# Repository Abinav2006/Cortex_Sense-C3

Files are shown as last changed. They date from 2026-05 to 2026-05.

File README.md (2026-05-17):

# CortexSense C3

A compact and intelligent 4-layer IoT development board powered by the ESP32-C3, designed for wireless sensing, environmental monitoring, AI-enabled edge applications, and rapid prototyping.

---

# Why the Name "CortexSense C3"?

The name **CortexSense C3** reflects the core philosophy of the board:

- **Cortex** represents intelligence, processing, and AI-driven capabilities.
- **Sense** highlights the board’s onboard sensing features such as environmental monitoring, ambient light detection, and audio input.
- **C3** refers to the ESP32-C3 microcontroller at the heart of the system.

Together, the name symbolizes an intelligent sensing platform capable of collecting, analyzing, and communicating real-world data.

---

# Overview

CortexSense C3 is a feature-rich embedded development platform combining wireless connectivity, onboard sensors, storage, battery support, and AI integration possibilities into a single compact PCB.

The board is built using a **4-layer PCB architecture** for improved signal integrity, grounding, and power distribution, making it suitable for reliable embedded and IoT applications.

This platform is ideal for:

- Environmental monitoring systems
- Wireless IoT nodes
- Portable data loggers
- AI-assisted embedded systems
- Voice-enabled smart devices
- Battery-powered sensing platforms
- Rapid embedded prototyping

---

# Hardware Features

## Microcontroller

### ESP32-C3
- RISC-V based architecture
- Wi-Fi connectivity
- Bluetooth Low Energy (BLE)
- USB support
- Low power operation
- Suitable for IoT and edge computing applications

---

# Power System

- USB-C power input
- LiPo battery connector
- Onboard 3.3V regulator
- Onboard 5V regulation circuitry
- Battery-powered operation support
- Power management circuitry

Designed for both:
- Portable battery-powered applications
- USB-powered desktop operation

---

# Storage

## MicroSD Card Slot
Supports:
- Sensor data logging
- Offline storage
- Audio recording
- Dataset collection

## External SPI Flash Memory
Useful for:
- Firmware storage
- Local caching
- AI model storage
- Configuration storage

---

# Sensors

## Environmental Sensor — BME280
Measures:
- Temperature
- Humidity
- Atmospheric pressure

Suitable for:
- Weather monitoring
- Indoor air analysis
- Smart agriculture
- Climate tracking

---

## Ambient Light Sensor
Features:
- Light intensity sensing
- Day/night detection
- Automatic brightness applications

---

## Audio Input System
Includes:
- Onboard microphone
- Audio pre-amplifier circuitry

Applications:
- Sound level monitoring
- Voice-controlled systems
- Acoustic analysis
- Smart assistants

---

# Interfaces

- I2C interface
- SPI interface
- GPIO expansion header
- USB-to-UART bridge
- Debug test points

Allows easy integration with:
- Displays
- External sensors
- Actuators
- Wireless modules
- Custom peripherals

---

# User Interaction

- Boot button
- Reset button
- Status LEDs
- GPIO headers

---

# PCB Design

## 4-Layer PCB Architecture

The board uses a professionally designed 4-layer PCB stackup for:

- Improved signal integrity
- Better grounding
- Reduced EMI
- Cleaner power distribution
- Compact routing

Additional design features:
- Dedicated debugging test points
- Optimized component placement
- Modular expansion capability

---

# Potential Applications

## Environmental Monitoring Station

CortexSense C3 can function as a compact weather and environmental monitoring system capable of tracking:

- Temperature
- Humidity
- Pressure
- Ambient light levels

Features include:
- Local logging to microSD
- Wireless cloud upload via Wi-Fi
- Remote monitoring dashboards
- Historical data storage

---

## Portable Data Logger

With battery support and onboard storage, the board is ideal for:

- Field research
- Agricultural monitoring
- Industrial sensing
- Mobile data collection

---

## Smart IoT Devices

The ESP32-C3 enables wireless communication for:

- Smart home systems
- Wireless sensor nodes
- BLE devices
- Remote monitoring applications

---

## Acoustic Monitoring

The onboard microphone system enables:

- Noise pollution monitoring
- Audio event detection
- Voice-triggered systems
- Environmental acoustic analysis

---

## Wearable Electronics

Its compact form factor and LiPo battery support make it suitable for:

- Wearable sensors
- Portable health devices
- Smart badges
- Mobile embedded systems

---

# AI and OpenAI Integration

One of the most exciting exploration areas for CortexSense C3 is embedded Artificial Intelligence.

Espressif provides OpenAI-compatible libraries and components for ESP32 platforms, enabling embedded devices to interact with Large Language Models (LLMs).

This opens the door to intelligent embedded applications capable of understanding and responding naturally.

---

# Voice-Controlled Smart Assistant

Using:
- The onboard microphone
- Wi-Fi connectivity
- OpenAI APIs

CortexSense C3 can become a conversational embedded assistant capable of:

- Understanding natural language
- Responding contextually
- Controlling smart devices
- Providing intelligent sensor analysis

Example interactions:

> “What is the current room temperature?”

> “Why is the humidity unusually high today?”

> “Turn on the lights.”

---

# Intelligent Environmental Insights

Instead of simply displaying raw sensor values, AI integration can:

- Analyze environmental trends
- Detect anomalies
- Generate human-readable summaries
- Recommend actions

Example:

> “Temperature has increased steadily for the last 3 hours. Consider watering the plants.”

---

# Future Improvements

Planned enhancements include:

- TinyML support
- Edge AI inference
- OTA firmware updates
- Display integration
- Additional sensor modules
- Ultra low-power optimization
- Custom enclosure development

---

# Software Support

CortexSense C3 can be programmed using:

- Arduino IDE
- ESP-IDF
- PlatformIO

---

# Recommended Libraries

## Connectivity
- WiFi
- BLE

## Storage
- SD card libraries
- SPIFFS

## Sensors
- BME280 drivers
- I2C utilities

## AI
- OpenAI ESP32 libraries

---

# Project Goals

The objective of CortexSense C3 is to create a flexible and expandable embedded platform for:

- IoT experimentation
- Wireless sensing
- Edge AI applications
- Embedded system learning
- Portable electronics development
- Rapid prototyping

---

# Getting Started

## Requirements

- USB-C cable
- ESP32 board support package
- Arduino IDE / ESP-IDF / PlatformIO
- Required sensor libraries

---

# Basic Workflow

1. Connect the board using USB-C
2. Install ESP32 board packages
3. Open the firmware project
4. Select the correct COM port
5. Build and flash firmware
6. Monitor serial output

---

# Images

## Front View

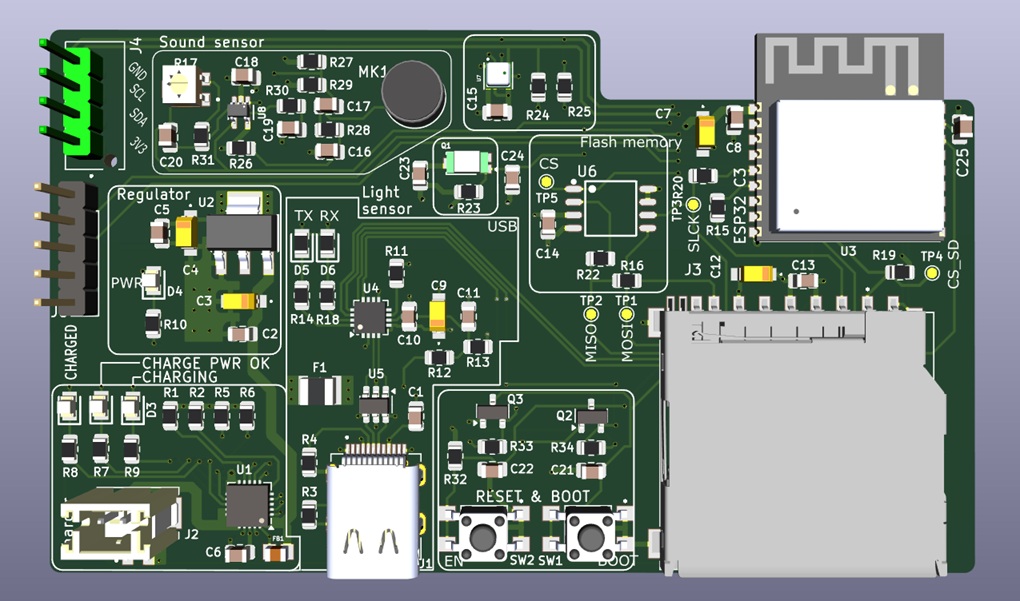
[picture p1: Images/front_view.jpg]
Front View


---

## Back View

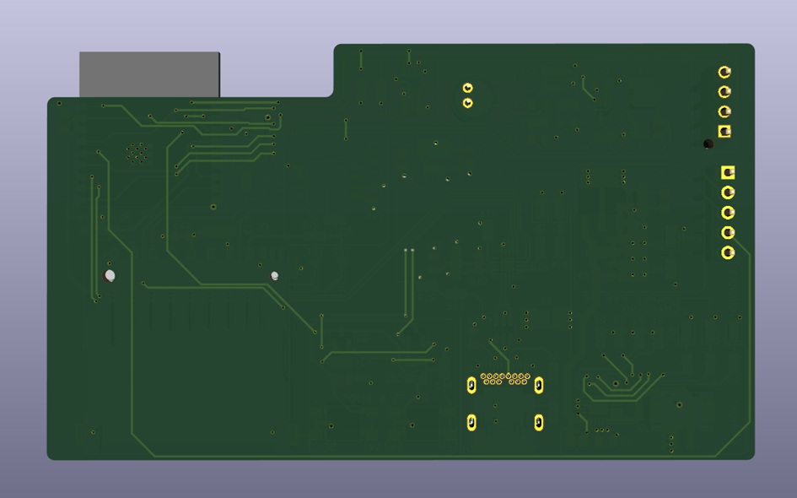
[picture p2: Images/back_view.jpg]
Back View


# License

This project is licensed under the MIT License.

```text
MIT License
```

---

# Acknowledgements

Special thanks to:

- Espressif Systems
- OpenAI
- Open-source embedded community

---

# Status

🚧 Under Active Development

Current Version:
```text
Rev A / v1.0
```

---

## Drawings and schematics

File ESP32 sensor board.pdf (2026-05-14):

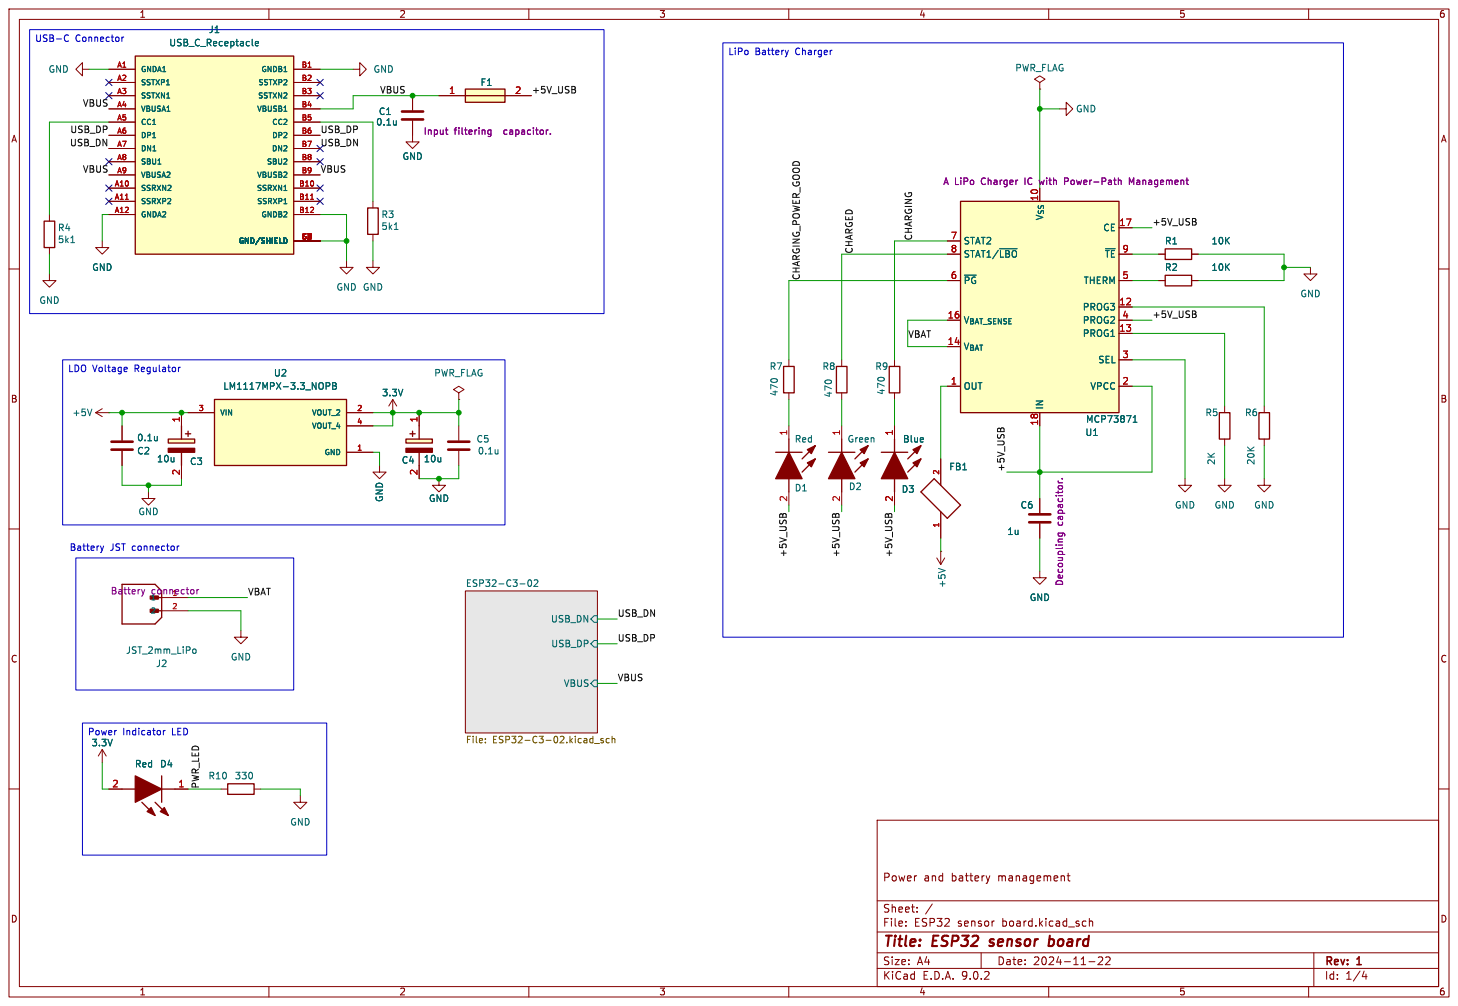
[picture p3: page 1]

1 2 R2 10K U1MCP73871 A LiPo Charger IC with Power-Path Management VPCC 2 SEL 3 PROG1 13 PROG2 4 PROG3 12 THERM 5 ~{TE}9 CE 17 IN 18 V_{SS} 10 OUT 1 V_{BAT} 14 V_{BAT_SENSE} 16 ~{PG} 6 STAT1/~{LBO} 8 STAT2 7 GND

Id: 1/4 Title: ESP32 sensor board

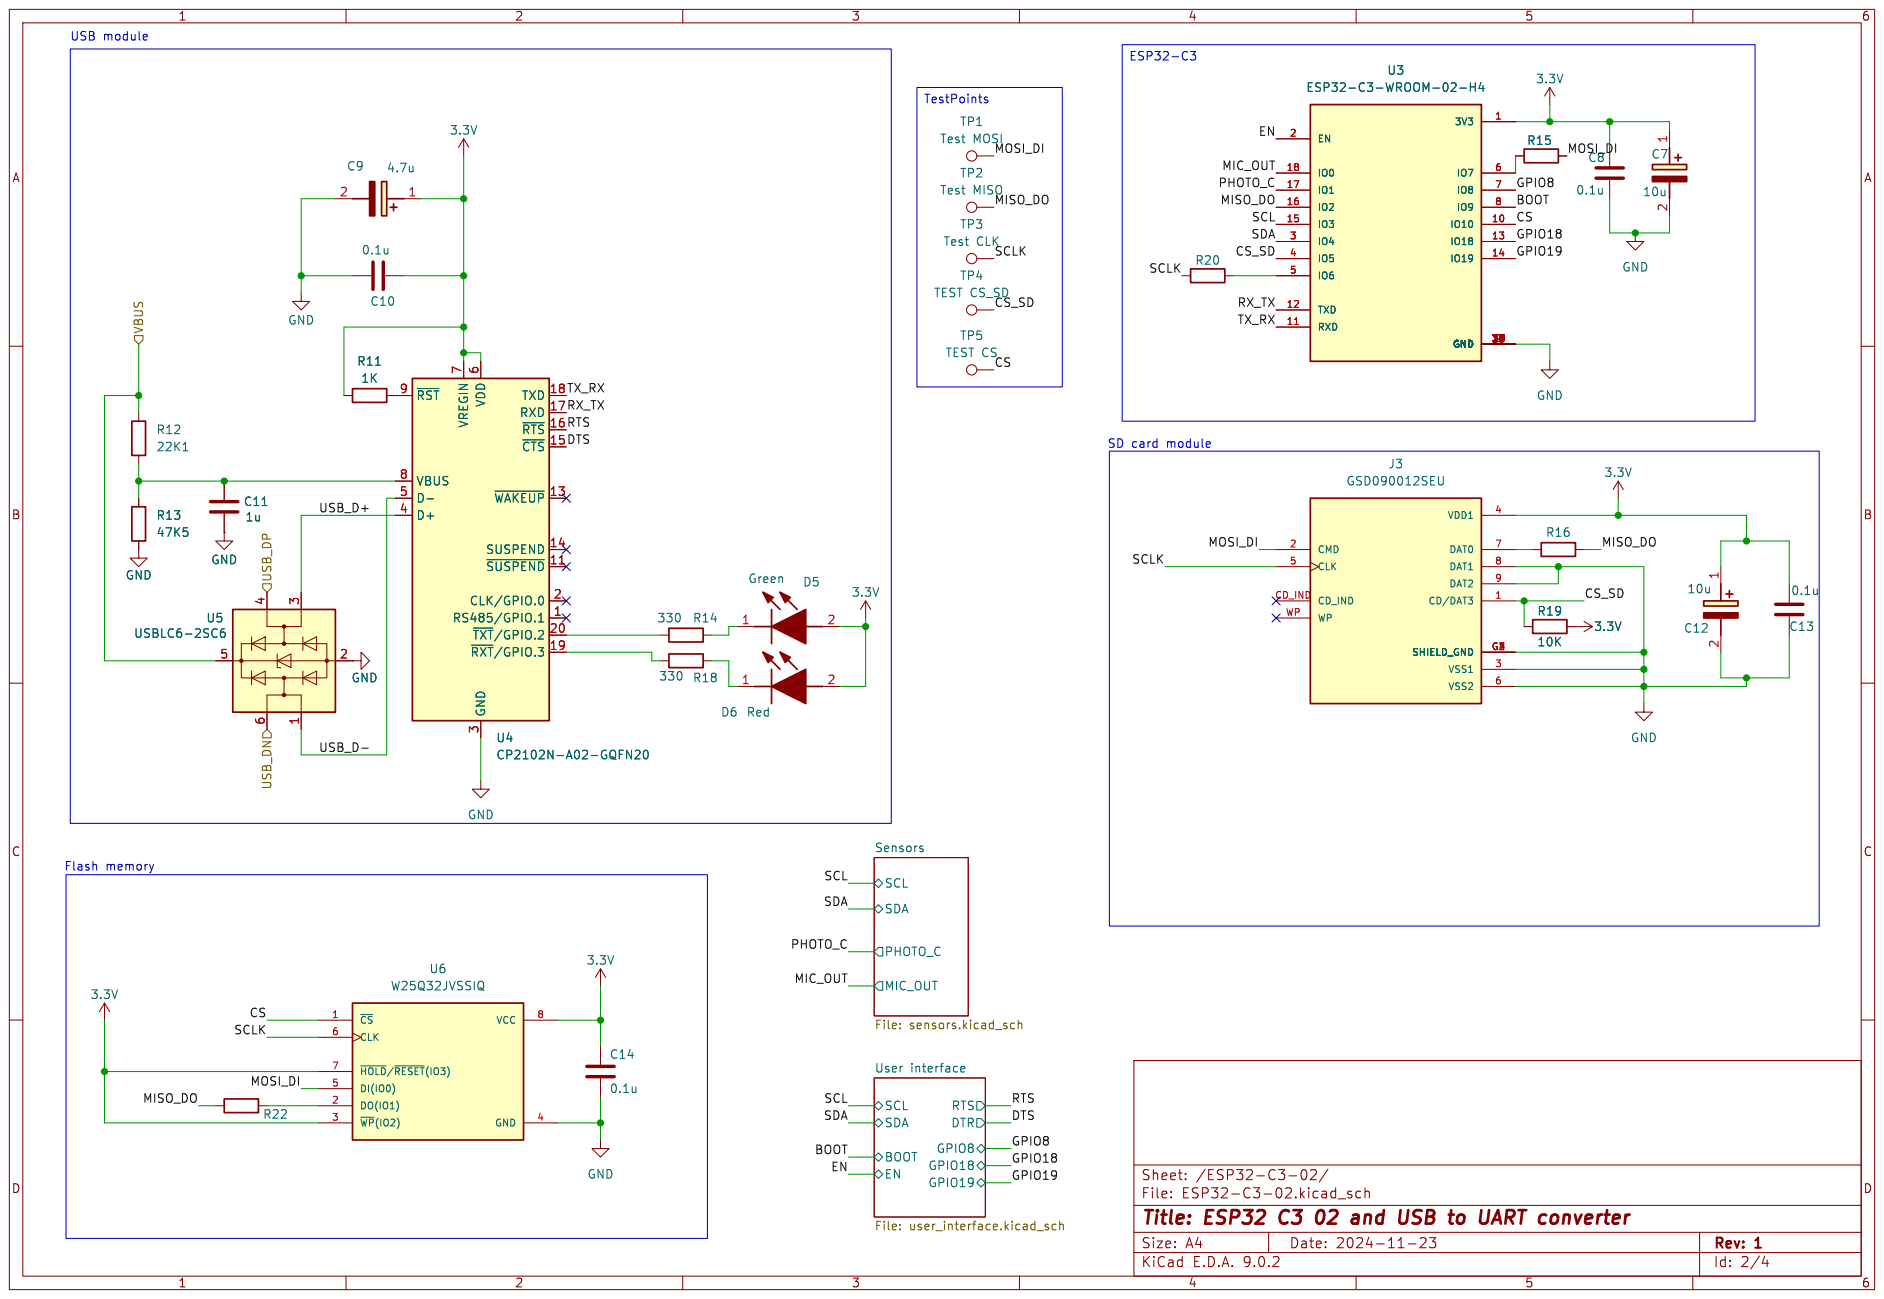
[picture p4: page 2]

TP1 Test MOSI TP2 Test MISO

3 TXD 18 RXD 17 ~{RTS} 16 ~{CTS} 15 ~{WAKEUP} 13 SUSPEND 14 ~{SUSPEND}11 CLK/GPIO.0 2 RS485/GPIO.1 1 ~{TXT}/GPIO.220 ~{RXT}/GPIO.319 C11

3 TXD 18 RXD 17 ~{RTS} 16 ~{CTS} 15 ~{WAKEUP} 13 SUSPEND 14 ~{SUSPEND}11 CLK/GPIO.0 2 RS485/GPIO.1 1 ~{TXT}/GPIO.220 ~{RXT}/GPIO.319 U4 CP2102N-A02-GQFN20 GND

PHOTO_C MIC_OUT Sensors File: sensors.kicad_sch SDA

Id: 2/4 Title: ESP32 C3 02 and USB to UART converter File: ESP32-C3-02.kicad_sch Sheet: /ESP32-C3-02/ SCL SDA
SCL SDA

DTR GPIO8 GPIO18 GPIO19 RTS User interface File: user_interface.kicad_sch
SCL BOOT EN

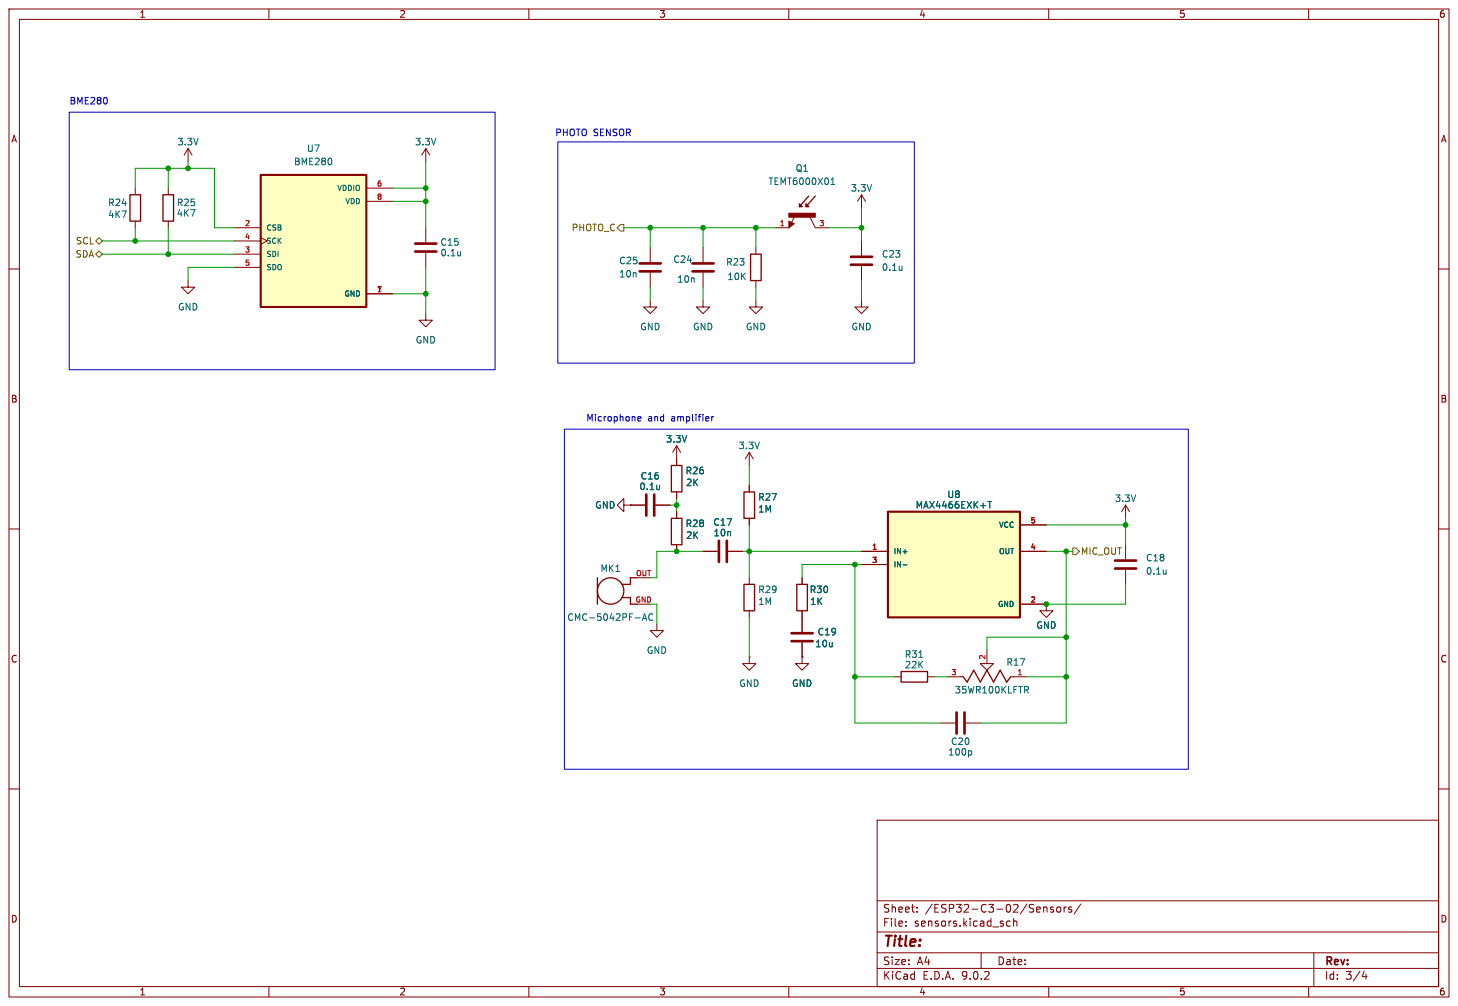
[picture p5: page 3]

OUT GND MK1 CMC-5042PF-AC

Id: 3/4 Title: File: sensors.kicad_sch Sheet: /ESP32-C3-02/Sensors/ 1

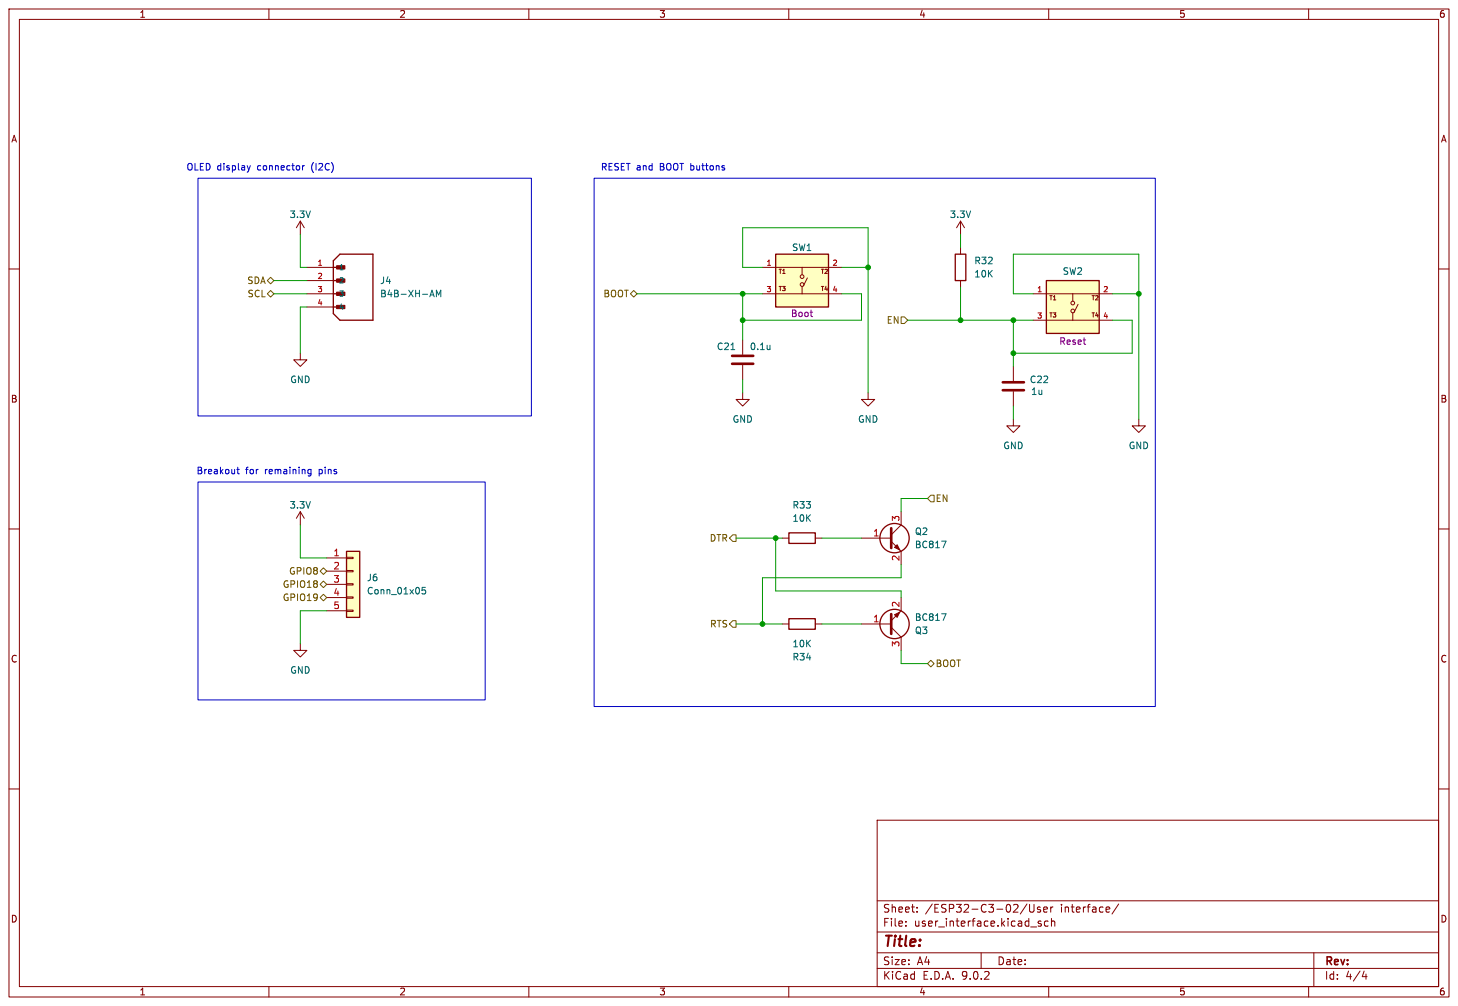
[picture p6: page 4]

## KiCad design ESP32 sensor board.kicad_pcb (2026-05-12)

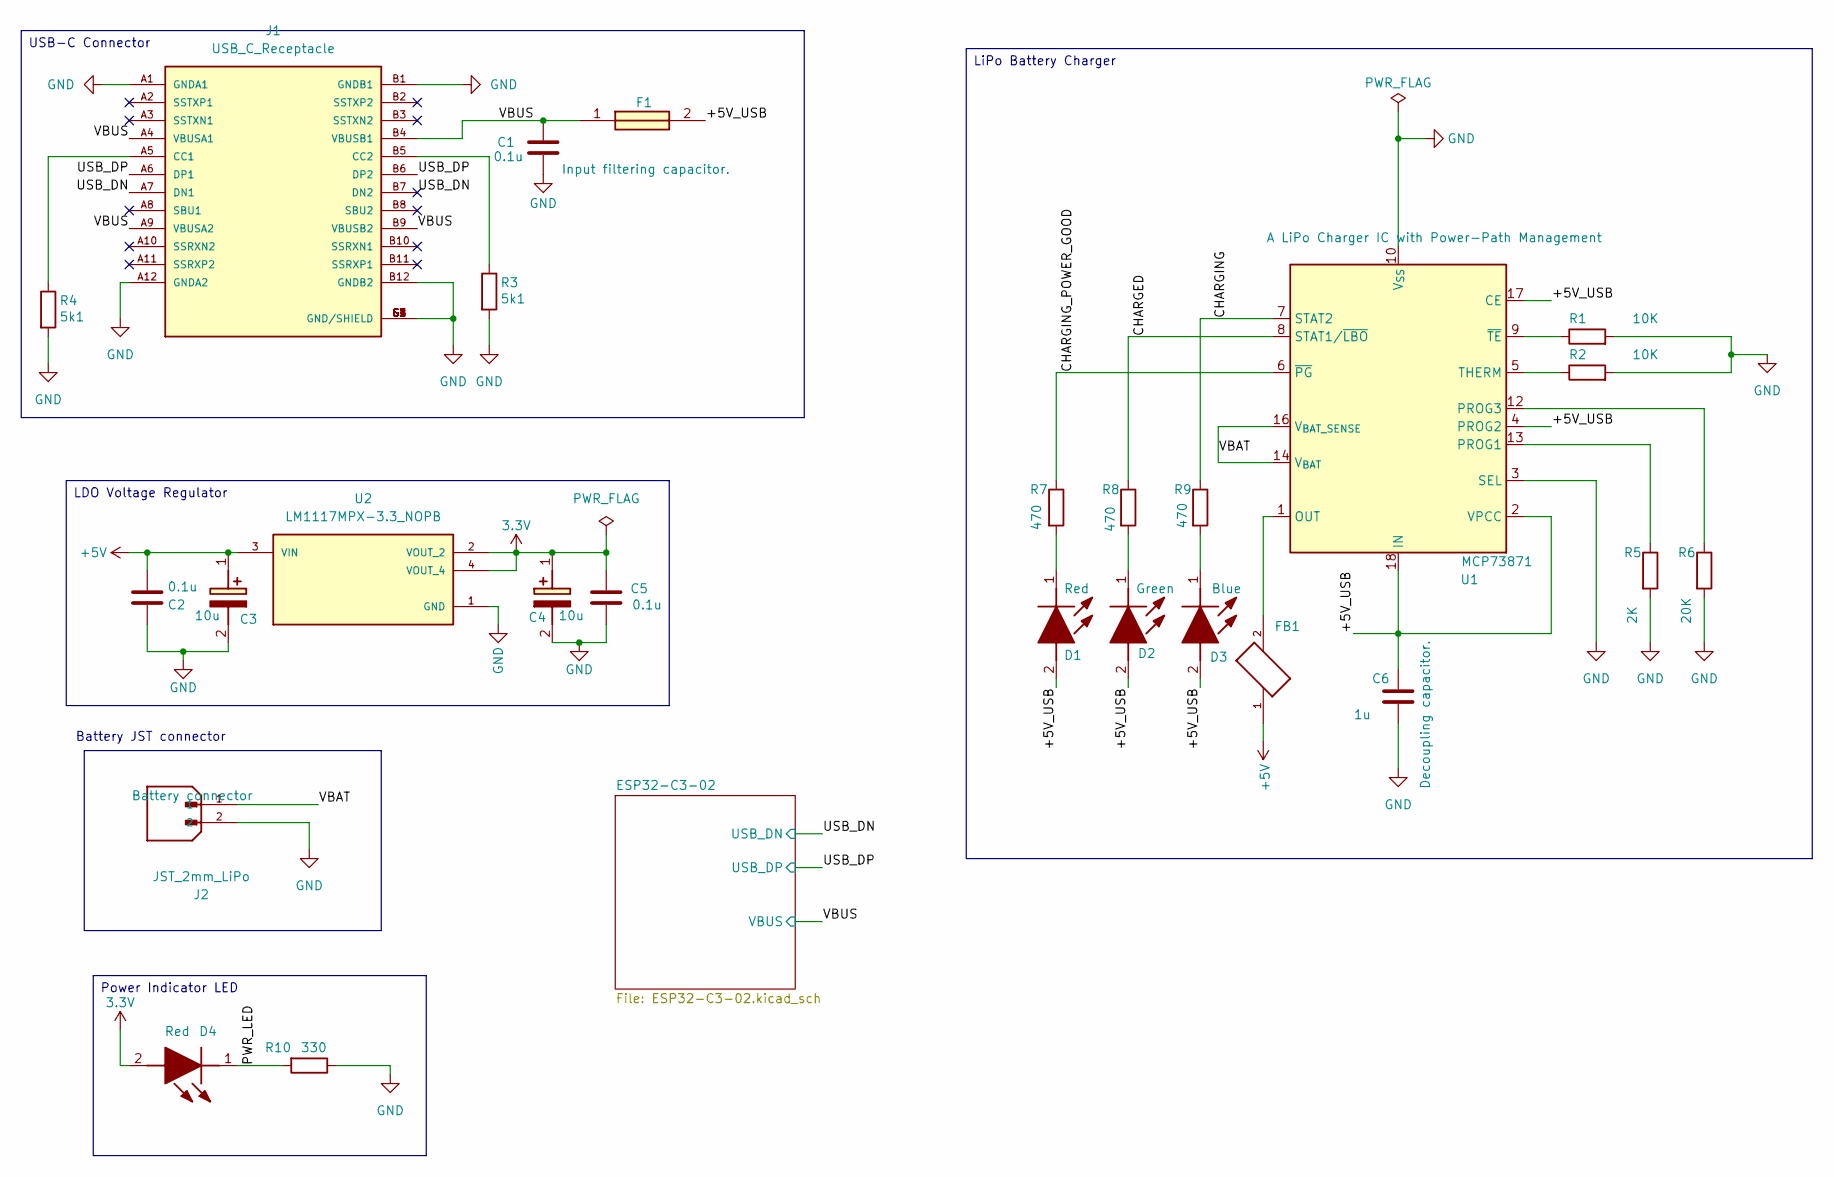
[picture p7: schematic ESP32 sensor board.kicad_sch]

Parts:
C1, C2, C5: 0.1u; C_0805_2012Metric; Voltage 1kV; Tolerance 100%
C3, C4: 10u; T491A; Voltage 1kV; Tolerance 100%; Manufacturer_Part_Number T491A106K010AT7280; Mouser Part Number 80-T491A106K107280
C6: 1u; C_0805_2012Metric; Voltage 1kV; Tolerance 100%
D1, D4: Red; LEDC2012X120N; Manufacturer_Part_Number LTST-C170KRKT; Mouser Part Number 859-LTST-C170KRKT
D2: Green; LEDC2012X120N; Manufacturer_Part_Number LTST-C170GKT; Mouser Part Number 859-LTST-C170GKT
D3: Blue; LEDC2012X120N; Manufacturer_Part_Number LTST-C170TBKT; Mouser Part Number 859-LTST-C170TBKT
F1: 0ZCH0110AF2E; FUSC3226X100N; Manufacturer_Part_Number 0ZCH0110AF2E
FB1: FBMJ2125HM330-T; BEADC2012X105N
J1: USB_C_Receptacle; BELFUSE_SS-52400-002; PARTREV A0
J2: JST_2mm_LiPo; JST_B2B-PH-SM4-TB; Manufacturer_Part_Number ?
R1, R2: 10K; R_0805_2012Metric
R3, R4: 5k1; R_0805_2012Metric
R5: 2K; R_0805_2012Metric
R6: 20K; R_0805_2012Metric
R7, R8, R9: 470; R_0805_2012Metric
R10: 330; R_0805_2012Metric
U1: MCP73871; QFN-20-1EP_4x4mm_P0.5mm_EP2.5x2.5mm; Manufacturer_Part_Number MCP73871-4CCI/ML
U2: LM1117MPX-3.3_NOPB; VREG_LM1117MPX-3.3; Mouser Part Number 926-LM1117MPX3.3NOPB

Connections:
3.3V: C4.1 (+), C5.1, D4.2 (A), U2.2 (VOUT_2), U2.4 (VOUT_4); also elsewhere on the board
+5V: C2.1, C3.1 (+), FB1.1, U2.3 (VIN)
/+5V_USB: C6.1, D1.2 (A), D2.2 (A), D3.2 (A), F1.2, U1.2 (VPCC), U1.4 (PROG2), U1.17 (CE), U1.18 (IN), U1.19 (IN)
/CHARGED: R8.1, U1.8 (STAT1/~LBO)
/CHARGING: R9.1, U1.7 (STAT2)
/CHARGING_POWER_GOOD: R7.1, U1.6 (~PG)
/PWR_LED: D4.1 (K), R10.2
/USB_DN: J1.A7 (DN1), J1.B7 (DN2); also elsewhere on the board
/USB_DP: J1.A6 (DP1), J1.B6 (DP2); also elsewhere on the board
/VBAT: J2.1, U1.14 (V_{BAT}), U1.15 (V_{BAT}), U1.16 (V_{BAT_SENSE})
/VBUS: C1.1, F1.1, J1.A4 (VBUSA1), J1.A9 (VBUSA2), J1.B4 (VBUSB1), J1.B9 (VBUSB2); also elsewhere on the board
unnamed: D1.1 (K), R7.2
unnamed: D2.1 (K), R8.2
unnamed: D3.1 (K), R9.2
unnamed: FB1.2, U1.1 (OUT), U1.20 (OUT)
unnamed: J1.A5 (CC1), R4.1
unnamed: J1.B5 (CC2), R3.1
unnamed: R5.1, U1.13 (PROG1)
unnamed: R6.1, U1.12 (PROG3)
unnamed: R2.1, U1.5 (THERM)
unnamed: R1.1, U1.9 (~TE)

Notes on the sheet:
Battery JST connector
LDO Voltage Regulator
LiPo Battery Charger
USB-C Connector
Power Indicator LED

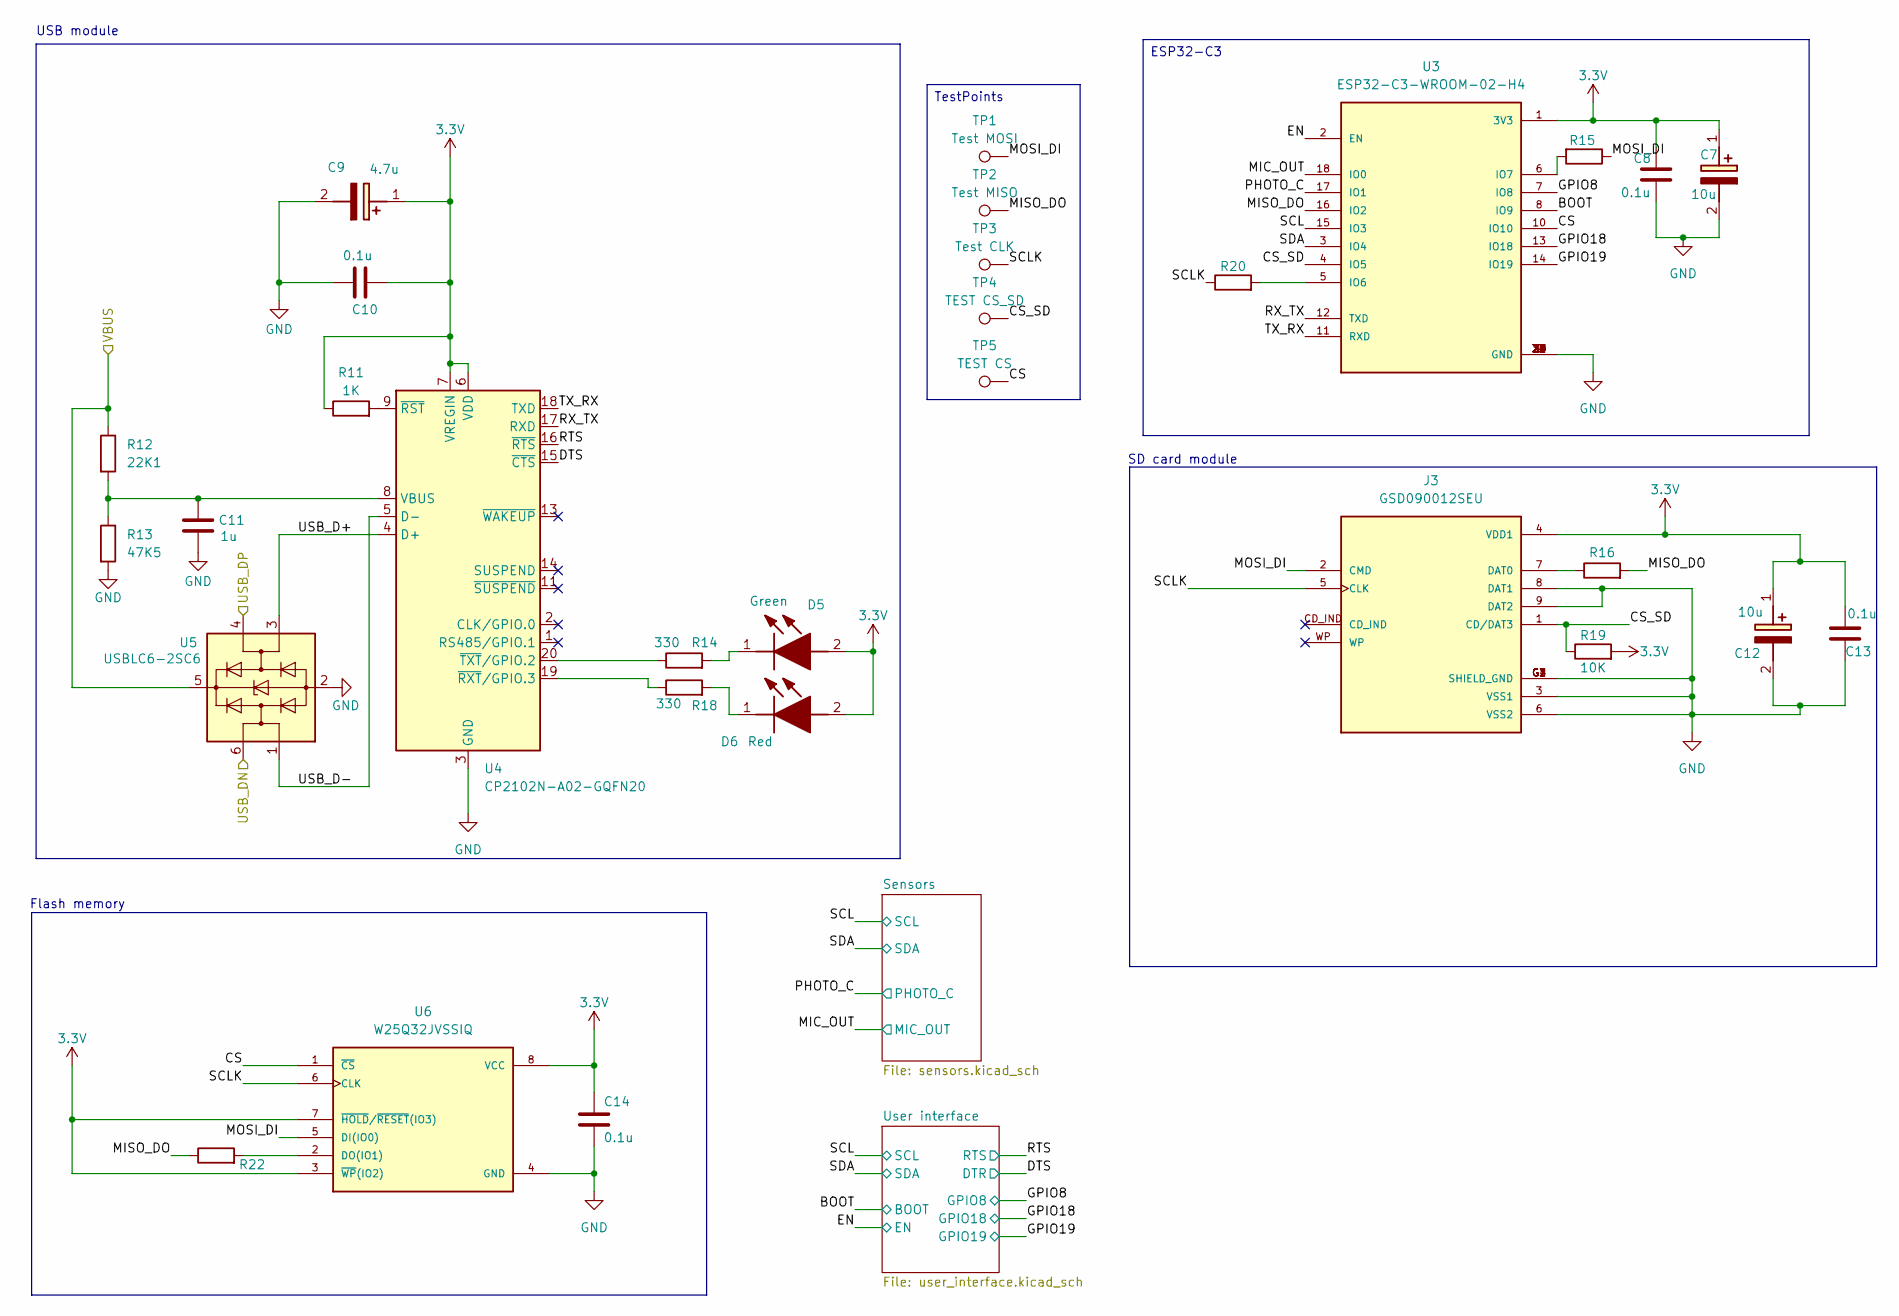
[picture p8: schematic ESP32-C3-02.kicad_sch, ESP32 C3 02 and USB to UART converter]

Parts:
C7, C12: 10u; T491A; Voltage 1kV; Tolerance 100%; Manufacturer_Part_Number T491A106K010AT7280; Mouser Part Number 80-T491A106K107280
C8, C10, C13, C14: 0.1u; C_0805_2012Metric; Voltage 1kV; Tolerance 100%
C9: 4.7u; T491A; Voltage 1kV; Tolerance 100%; Manufacturer_Part_Number T491A106K010AT7280; Mouser Part Number 80-T491A106K107280
C11: 1u; C_0805_2012Metric; Voltage 1kV; Tolerance 100%
D5: Green; LEDC2012X120N; Manufacturer_Part_Number LTST-C170GKT; Mouser Part Number 859-LTST-C170GKT
D6: Red; LEDC2012X120N; Manufacturer_Part_Number LTST-C170KRKT; Mouser Part Number 859-LTST-C170KRKT
J3: GSD090012SEU; AMPHENOL_GSD090012SEU; PARTREV E
R11: 1K; R_0805_2012Metric
R12: 22K1; R_0805_2012Metric
R13: 47K5; R_0805_2012Metric
R14, R18: 330; R_0805_2012Metric
R15, R16, R20, R22: 50; R_0805_2012Metric
R19: 10K; R_0805_2012Metric
TP1: Test MOSI; TestPoint_Pad_D1.0mm
TP2: Test MISO; TestPoint_Pad_D1.0mm
TP3: Test CLK; TestPoint_Pad_D1.0mm
TP4: TEST CS_SD; TestPoint_Pad_D1.0mm
TP5: TEST CS; TestPoint_Pad_D1.0mm
U3: ESP32-C3-WROOM-02-H4; MODULE_ESP32-C3-WROOM-02-H4; Manufacturer_Part_Number ESP32-C3-WROOM-02-H4
U4: CP2102N-A02-GQFN20; SiliconLabs_QFN-20-1EP_3x3mm_P0.5mm_EP1.8x1.8mm; Manufacturer_Part_Number CP2102N-A02-GQFN20
U5: USBLC6-2SC6; SOT-23-6; Manufacturer_Part_Number USBLC6-2SC6; Mouser Part Number 511-USBLC6-2SC6
U6: W25Q32JVSSIQ; SOIC127P790X216-8N; M_PART_NUMBER W25QXX

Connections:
3.3V: C7.1 (+), C8.1, C9.1 (+), C10.1, C12.1 (+), C13.2, C14.1, D5.2 (A), D6.2 (A), J3.4 (VDD1), R11.1, R19.2, U3.1 (3V3), U4.6 (VDD), U4.7 (VREGIN), U6.3 (~WP(IO2)), U6.7 (~HOLD/~RESET(IO3)), U6.8 (VCC); also elsewhere on the board
/ESP32-C3-02/CS: TP5.1, U3.10 (IO10), U6.1 (~CS)
/ESP32-C3-02/CS_SD: J3.1 (CD/DAT3), R19.1, TP4.1, U3.4 (IO5)
/ESP32-C3-02/DTS: U4.15 (~CTS); also elsewhere on the board
/ESP32-C3-02/GPIO8: U3.7 (IO8); also elsewhere on the board
/ESP32-C3-02/GPIO18: U3.13 (IO18); also elsewhere on the board
/ESP32-C3-02/GPIO19: U3.14 (IO19); also elsewhere on the board
/ESP32-C3-02/MIC_OUT: U3.18 (IO0); also elsewhere on the board
/ESP32-C3-02/MISO_DO: R16.2, R22.1, TP2.1, U3.16 (IO2)
/ESP32-C3-02/MOSI_DI: J3.2 (CMD), R15.1, TP1.1, U6.5 (DI(IO0))
/ESP32-C3-02/PHOTO_C: U3.17 (IO1); also elsewhere on the board
/ESP32-C3-02/RTS: U4.16 (~RTS); also elsewhere on the board
/ESP32-C3-02/RX_TX: U3.12 (TXD), U4.17 (RXD)
/ESP32-C3-02/SCL: U3.15 (IO3); also elsewhere on the board
/ESP32-C3-02/SCLK: J3.5 (CLK), R20.1, TP3.1, U6.6 (CLK)
/ESP32-C3-02/SDA: U3.3 (IO4); also elsewhere on the board
/ESP32-C3-02/TX_RX: U3.11 (RXD), U4.18 (TXD)
/ESP32-C3-02/USB_D+: U4.4 (D+), U5.3 (I/O2)
/ESP32-C3-02/USB_D-: U4.5 (D-), U5.1 (I/O1)
/USB_DN: U5.6 (I/O1); also elsewhere on the board
/USB_DP: U5.4 (I/O2); also elsewhere on the board
/VBUS: R12.1, U5.5 (VBUS); also elsewhere on the board
unnamed: D5.1 (K), R14.2
unnamed: D6.1 (K), R18.2
unnamed: J3.7 (DAT0), R16.1
unnamed: R20.2, U3.5 (IO6)
unnamed: R15.2, U3.6 (IO7)
unnamed: C11.1, R12.2, R13.1, U4.8 (VBUS)
unnamed: R11.2, U4.9 (~RST)
unnamed: R18.1, U4.19 (~RXT/GPIO.3)
unnamed: R14.1, U4.20 (~TXT/GPIO.2)
unnamed: R22.2, U6.2 (DO(IO1))

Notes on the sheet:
SD card module
Flash memory
USB module
ESP32-C3
TestPoints

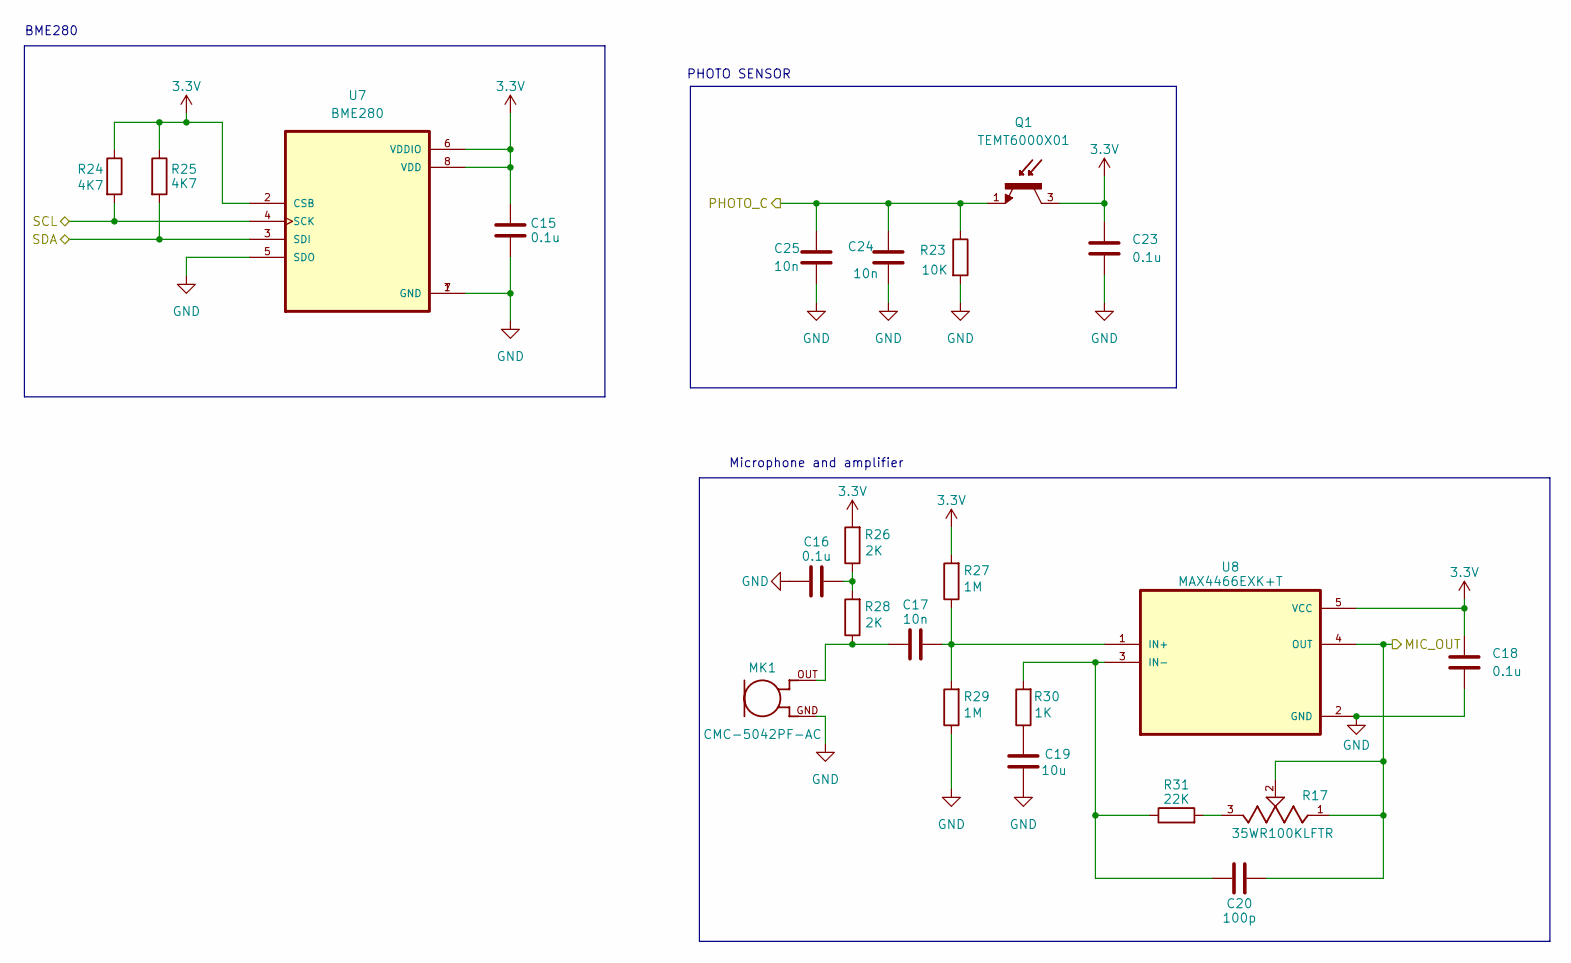
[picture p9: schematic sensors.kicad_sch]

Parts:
C15: 0.1u; C_0805_2012Metric; Voltage 1kV; Tolerance 100%
C16, C18, C23: 0.1u; C_0805_2012Metric
C17, C24, C25: 10n; C_0805_2012Metric
C19: 10u; C_0805_2012Metric
C20: 100p; C_0805_2012Metric
MK1: CMC-5042PF-AC; CUI_CMC-5042PF-AC; Manufacturer_Part_Number CMC-5042PF-AC
Q1: TEMT6000X01; TRANS_TEMT6000X01; PARTREV 1.9
R17: 35WR100KLFTR; TRIM_35WR100KLFTR; PARTREV D
R23: 10K; R_0805_2012Metric
R24, R25: 4K7; R_0805_2012Metric
R26, R28: 2K; R_0805_2012Metric
R27, R29: 1M; R_0805_2012Metric
R30: 1K; R_0805_2012Metric
R31: 22K; R_0805_2012Metric
U7: BME280; PSON65P250X250X100-8N; Manufacturer_Part_Number BME280
U8: MAX4466EXK+T; SOT65P210X110-5N; Manufacturer_Part_Number MAX4466EXK+T

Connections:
3.3V: C15.2, C18.1, C23.1, Q1.3, R24.1, R25.1, R26.2, R27.2, U7.2 (CSB), U7.6 (VDDIO), U7.8 (VDD), U8.5 (VCC); also elsewhere on the board
/ESP32-C3-02/MIC_OUT: C20.2, R17.1, R17.2, U8.4 (OUT); also elsewhere on the board
/ESP32-C3-02/PHOTO_C: C24.1, C25.1, Q1.1, R23.1; also elsewhere on the board
/ESP32-C3-02/SCL: R24.2, U7.4 (SCK); also elsewhere on the board
/ESP32-C3-02/SDA: R25.2, U7.3 (SDI); also elsewhere on the board
unnamed: C16.1, R26.1, R28.2
unnamed: C17.2, MK1.OUT, R28.1
unnamed: C19.2, R30.1
unnamed: R17.3, R31.2
unnamed: C17.1, R27.1, R29.2, U8.1 (IN+)
unnamed: C20.1, R30.2, R31.1, U8.3 (IN-)

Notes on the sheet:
PHOTO SENSOR
Microphone and amplifier
BME280

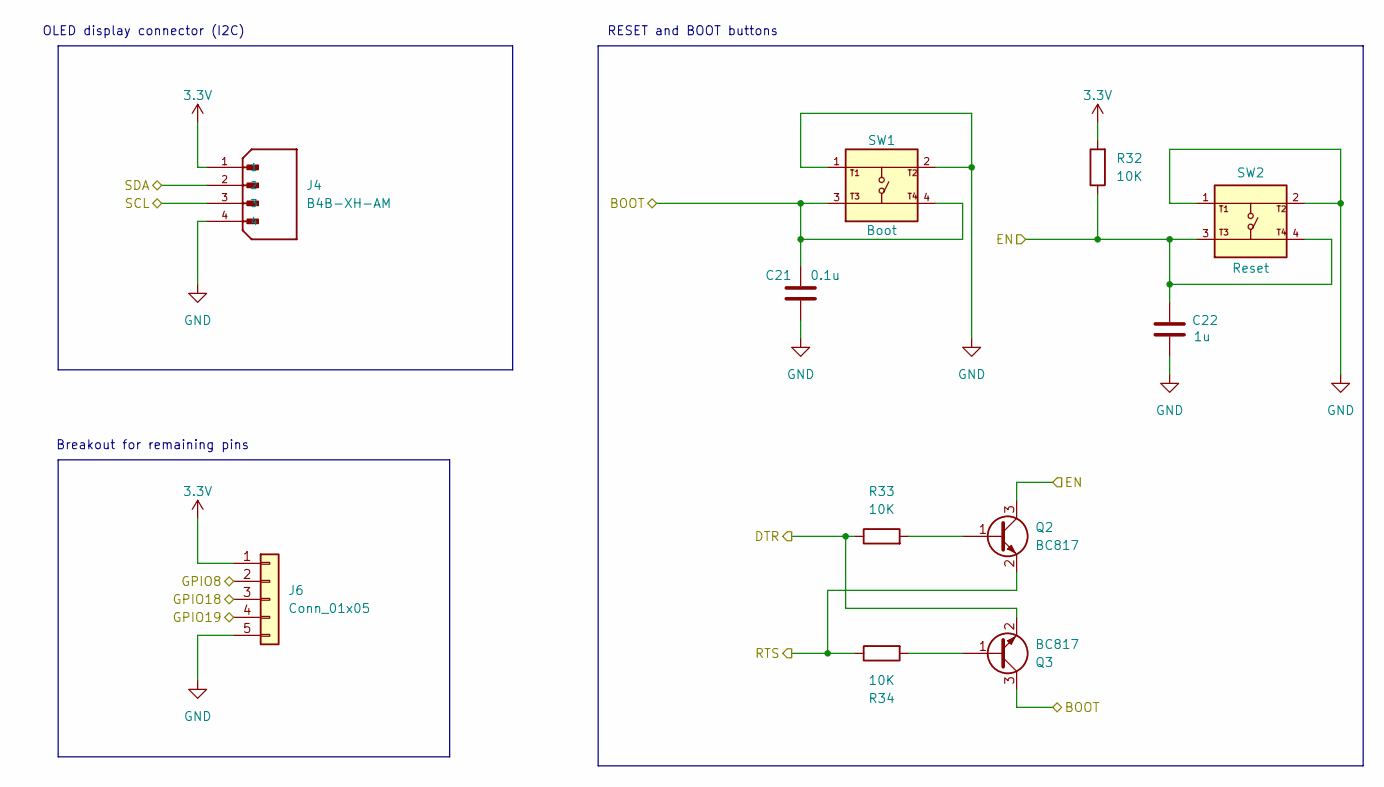
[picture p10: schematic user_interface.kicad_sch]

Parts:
C21: 0.1u; C_0805_2012Metric; Voltage 1kV; Tolerance 100%
C22: 1u; C_0805_2012Metric; Voltage 1kV; Tolerance 100%
J4: B4B-XH-AM; JST_B4B-XH-AM__LF__SN_; PARTREV N/A
J6: Conn_01x05; PinHeader_1x05_P2.54mm_Vertical
Q2, Q3: BC817; SOT-23; Manufacturer_Part_Number BC817
R32, R33, R34: 10K; R_0805_2012Metric
SW1, SW2: 1101NE; SW_USLPT2819DT2TR; Mfg Part# 8-004 SMD Button 8x3.6mm Height=2.5mm

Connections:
3.3V: J4.1, J6.1, R32.2; also elsewhere on the board
/ESP32-C3-02/DTS: Q3.2 (E), R33.1; also elsewhere on the board
/ESP32-C3-02/GPIO8: J6.2; also elsewhere on the board
/ESP32-C3-02/GPIO18: J6.3; also elsewhere on the board
/ESP32-C3-02/GPIO19: J6.4; also elsewhere on the board
/ESP32-C3-02/RTS: Q2.2 (E), R34.1; also elsewhere on the board
/ESP32-C3-02/SCL: J4.3; also elsewhere on the board
/ESP32-C3-02/SDA: J4.2; also elsewhere on the board
unnamed: Q2.1 (B), R33.2
unnamed: Q3.1 (B), R34.2

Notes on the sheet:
OLED display connector (I2C)
RESET and BOOT buttons
Breakout for remaining pins

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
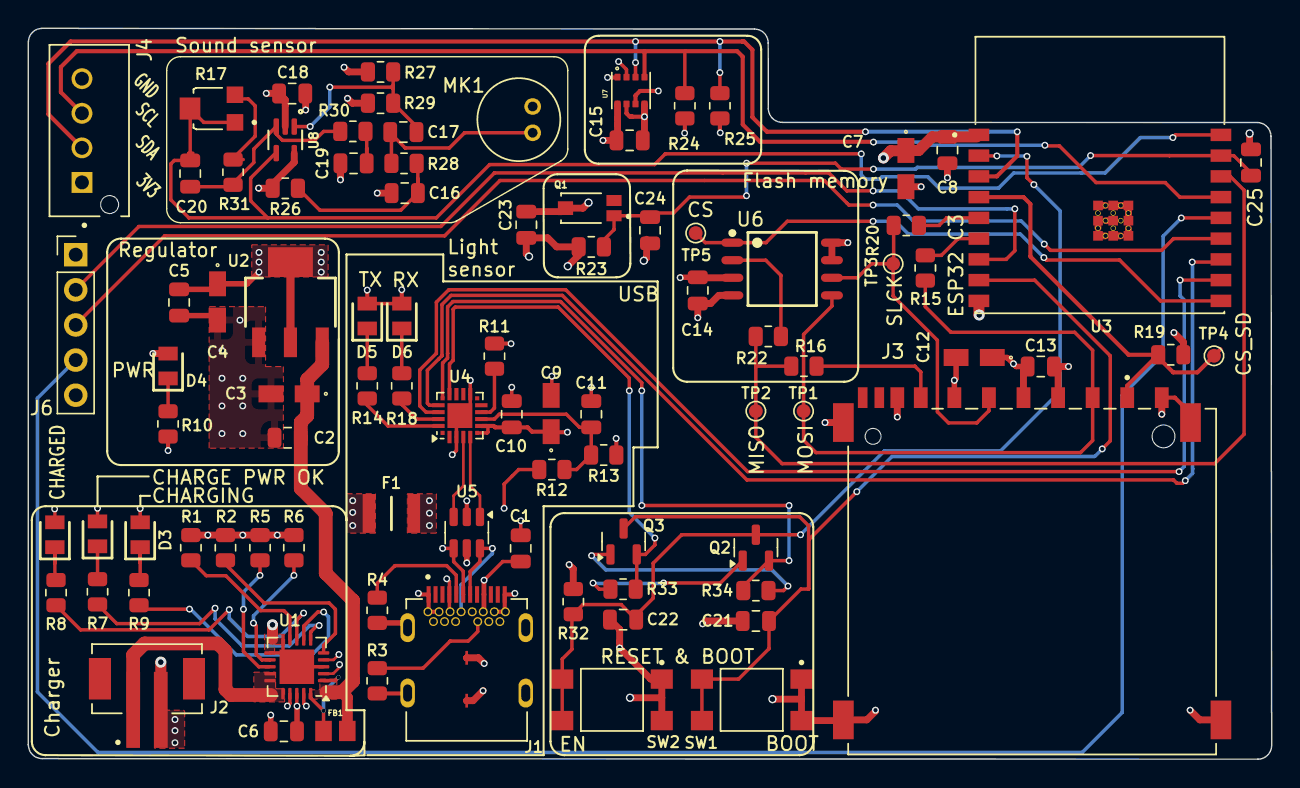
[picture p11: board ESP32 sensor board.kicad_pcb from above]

Board: 4 copper layers, 89.9 x 52.8 mm, 90 parts (0 on the bottom side), 60 nets.

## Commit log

2026-05-12 feat : Symbols, Footprints and 3D models for the components
2026-05-12 feat : kicad project files
    [ESP32 sensor board.kicad_pcb, ESP32 sensor board.kicad_sch, ESP32-C3-02.kicad_sch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]
2026-05-12 feat : Image of the PCB
2026-05-14 feat : PCB Schemat PDF
